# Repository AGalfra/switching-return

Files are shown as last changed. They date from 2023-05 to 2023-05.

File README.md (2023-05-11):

# Conmutador de Retorno

## I. INTRODUCCIÓN
A pesar de la creciente demanda de servicios FTTH (Fiber To The Home), se puede decir que hoy en
día el despliegue de redes de HFC (Hybrid Fibre Coaxial) puede considerarse bastante masivo.
Para mantener los estándares de salud de red que la empresa exige y mejorar la experiencia del
cliente es que se trabaja exhaustivamente en tareas de mantenimiento preventivo.
El mayor problema de este tipo de redes es debido a la interferencia generada por las instalaciones
domiciliarias defectuosas y sobre todo a la alta tasa de conexiones clandestinas que son las mayores
generadoras de interferencias. Debido a esto es que aproximadamente el 90% de las intervenciones
en este tipo de redes es por los problemas antes mencionados. La cual es una tarea que demanda
demasiado tiempo y costo operativo.
Es por ello, que se propone el diseño de una herramienta que ayude a optimizar los tiempos de
trabajo y agilizar las tareas de búsqueda de interferencias.

## II. OBJETIVO
Diseño de un dispositivo que será utilizado como una herramienta adicional y complementaria a las
existentes para facilitar las tareas de mantenimiento en redes HFC, específicamente simplificar la
búsqueda de ruido y detección de interferencias en la banda de UPSTREAM en los nodos.

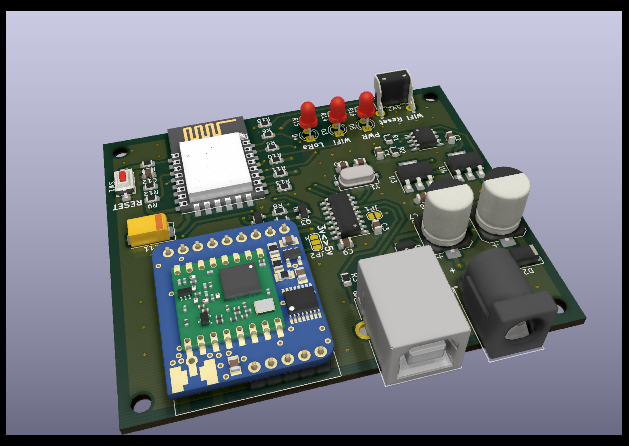
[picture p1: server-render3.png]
server

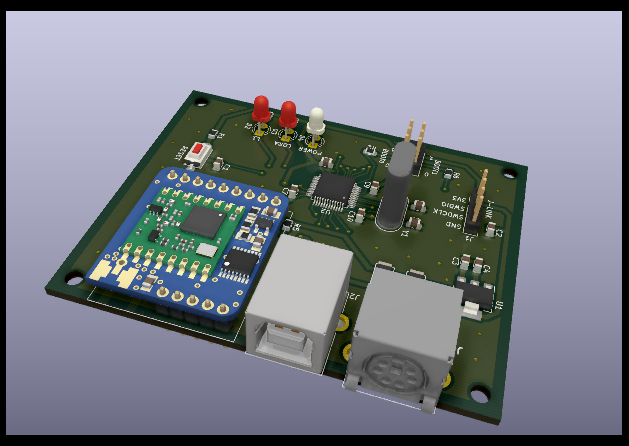
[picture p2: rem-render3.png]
remoto


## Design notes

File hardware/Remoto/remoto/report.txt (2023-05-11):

Anotado 1M como R7
Anotado Boot_Selector como J3
Anotado Mini-DIN-6 como J4
Anotado 10K como R1
Anotado 100K como R2
Anotado 20R como R3
Anotado 20R como R4
Anotado 10K como R5
Anotado 100K como R6
Anotado USB_B como J2
Anotado 1K como R8
Anotado 1K como R9
Anotado 1K como R10
Anotado SW_Reset como SW1
Anotado AMS1117-3.3 como U1
Anotado STM32F103C8Tx como U2
Anotado 8MHz como Y1
Anotado 105 como C1
Anotado J-Link como J1
Anotado RFM95W como IC1
Anotado LED como D4
Anotado LED como D3
Anotado LED como D2
Anotado SS14 como D1
Anotado 104 como C10
Anotado 104 como C9
Anotado 104 como C8
Anotado 104 como C7
Anotado 22pF como C6
Anotado 22pF como C5
Anotado C como C4
Anotado C como C3
Anotado 104 como C2

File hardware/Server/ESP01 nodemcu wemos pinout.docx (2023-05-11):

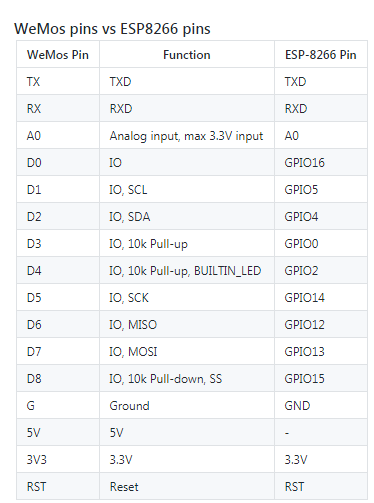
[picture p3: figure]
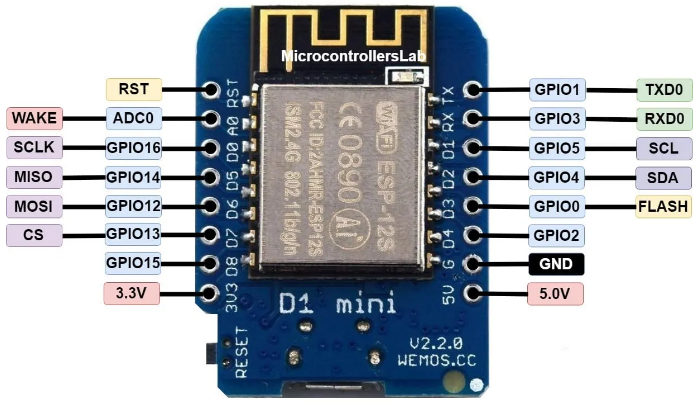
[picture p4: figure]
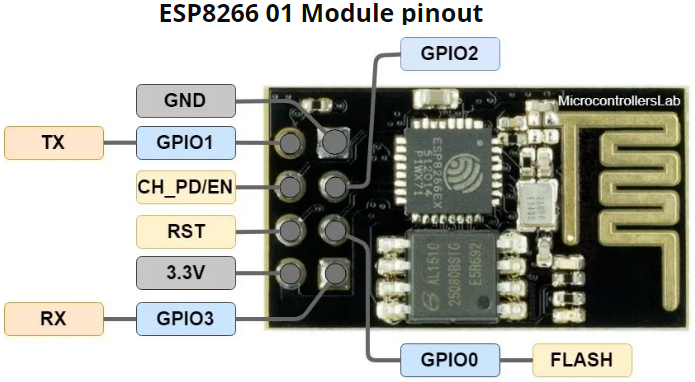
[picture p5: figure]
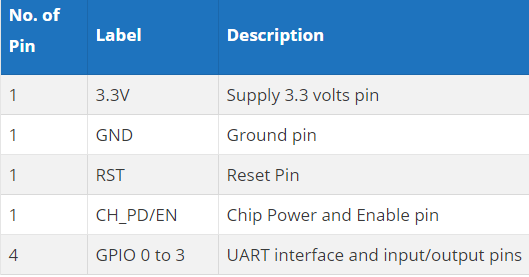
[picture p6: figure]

https://www.luisllamas.es/detalles-del-esp8266-diferencias-con-arduino/

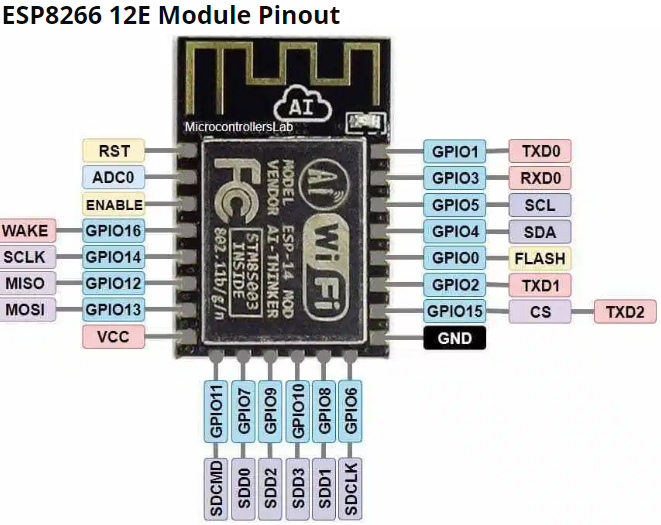
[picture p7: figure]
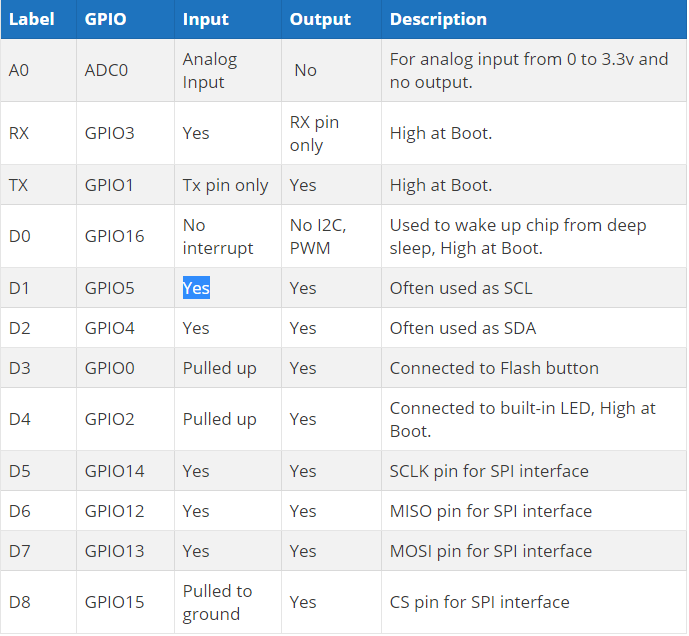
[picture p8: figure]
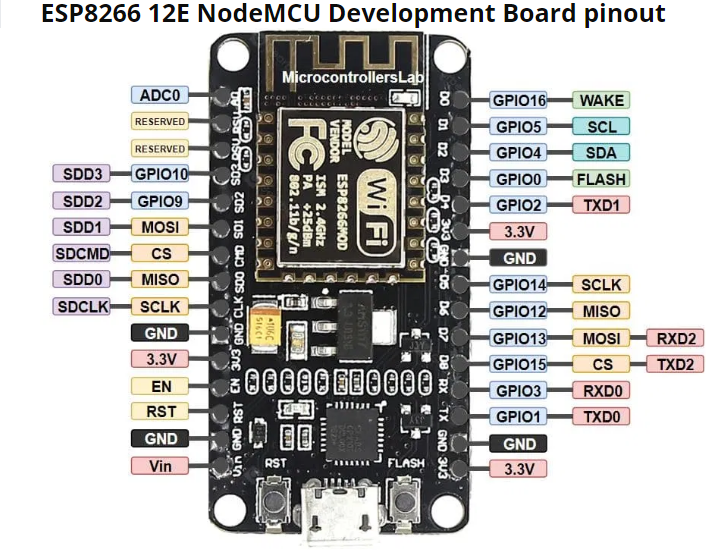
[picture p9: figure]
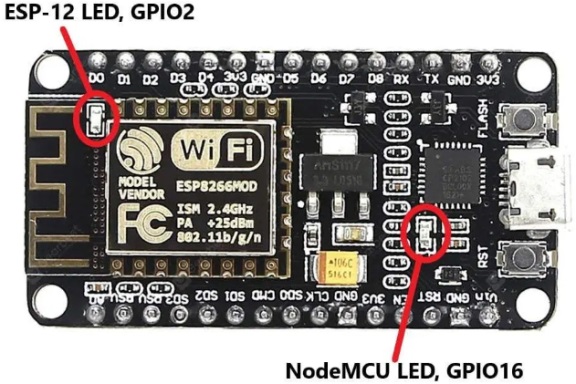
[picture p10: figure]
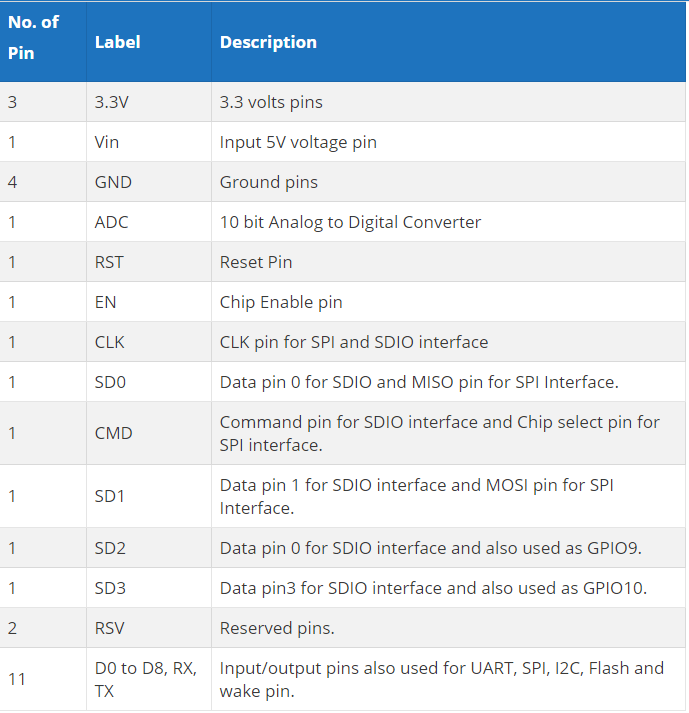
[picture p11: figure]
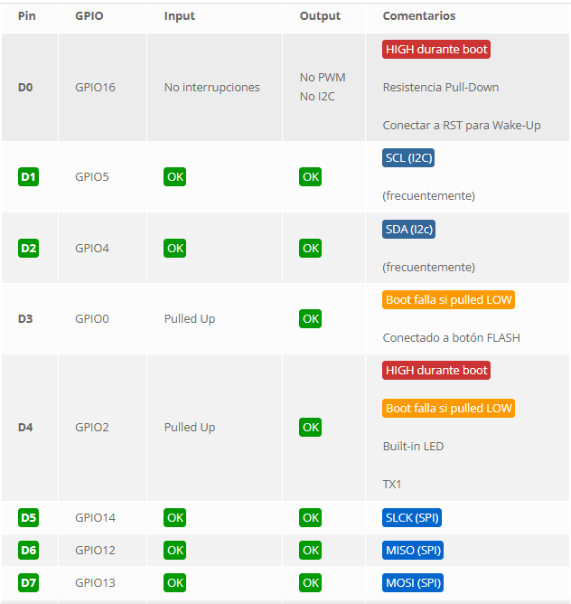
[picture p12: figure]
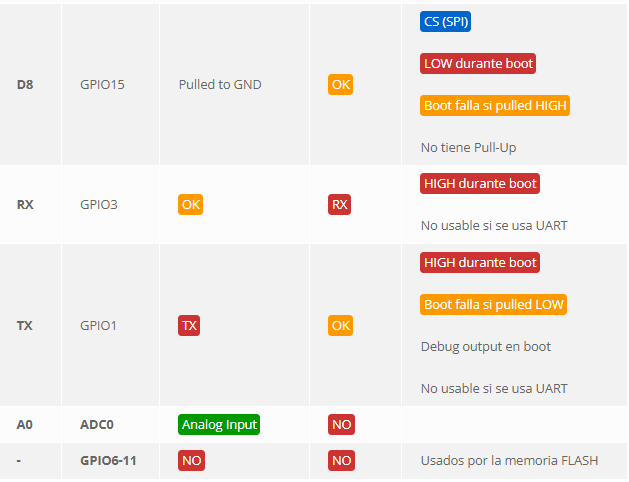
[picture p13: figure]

ESP32 de 30 pines LuaNode:

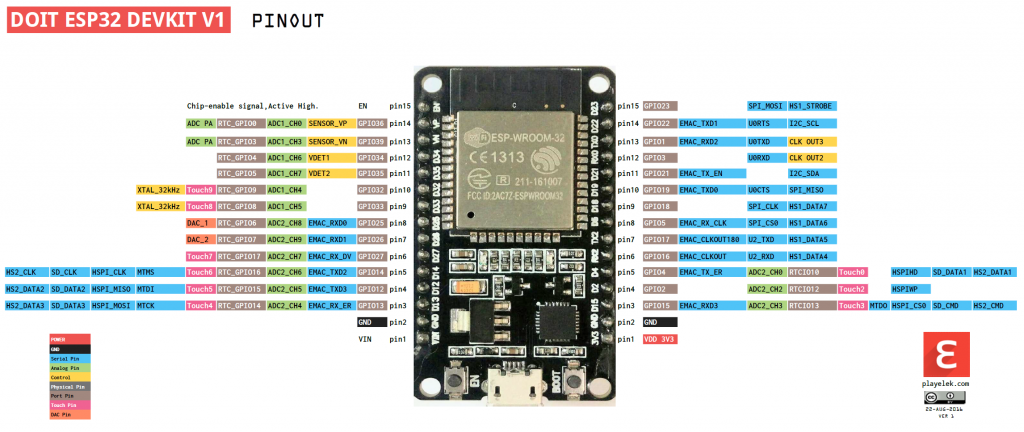
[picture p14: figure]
Mapeo de pines ESP32

Algunos pines GPIO se utilizan para configurar el cargador de arranque o el modo de flasheo de ESP32 durante el flasheo o la carga de arranque de la aplicación.

- GPIO0
- GPIO2
- GPIO4
- GPIO5 (debe estar ALTO durante el arranque)
- GPIO12 (debe estar BAJO durante el arranque)
- GPIO15 (debe ser ALTO durante el arranque)

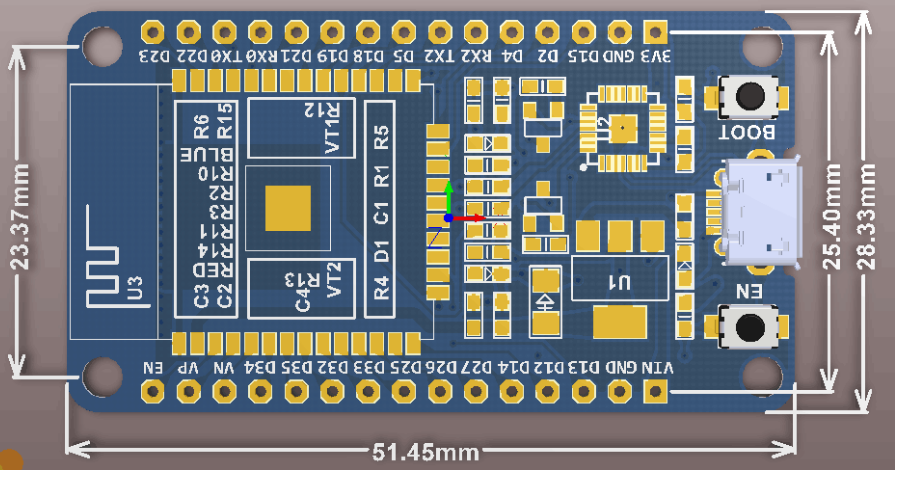
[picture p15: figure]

ESquematico: https://www.dropbox.com/s/jefwxxtufgwg0ex/esp32_Schematic%20Prints.pdf?dl=0

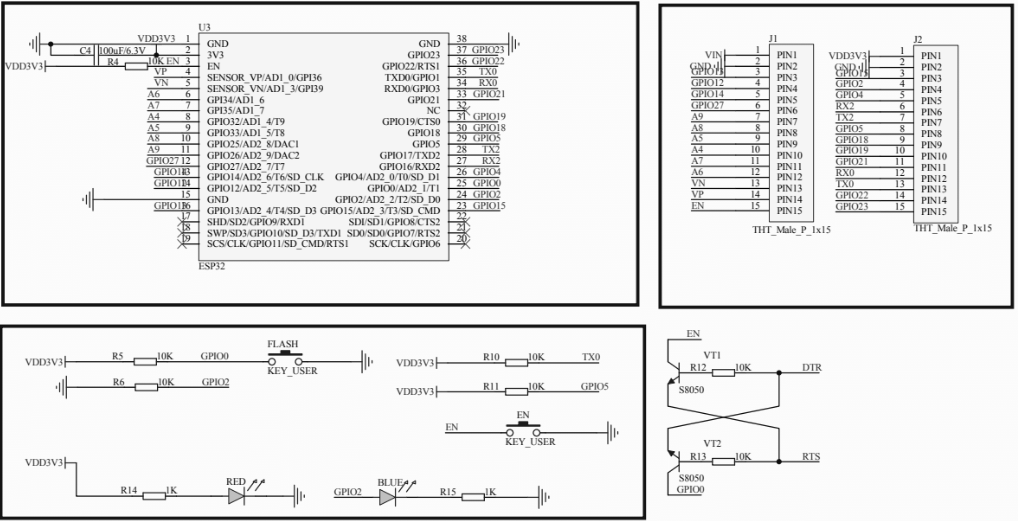
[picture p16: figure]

ESP32s – 38 PINES

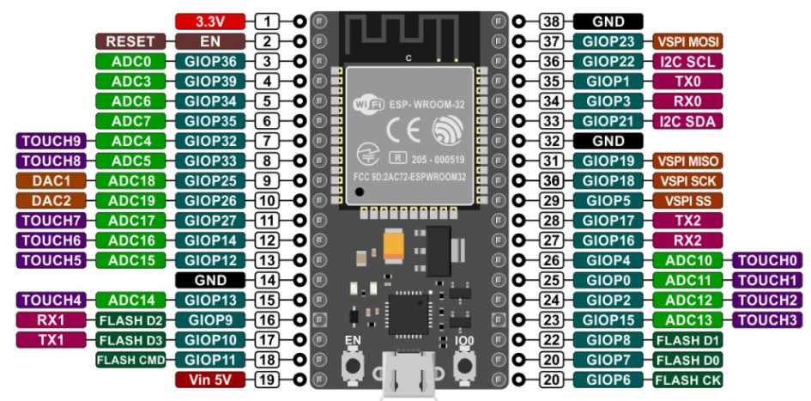
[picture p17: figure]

Configuración de Pines y asociación en el ARDUINO IDE

Alias | GPIO | Alias | GPIO | Alias | GPIO
D0 | 3 | D6 | 12 | D12 | 12
D1 | 1 | D7 | 13 | D13 | 14
D2 | 16 | D8 | 0 | D14 | 4
D3 | 5 | D9 | 2 | D15 | 5
D4 | 4 | D10 | 15
D5 | 14 | D11 | 13

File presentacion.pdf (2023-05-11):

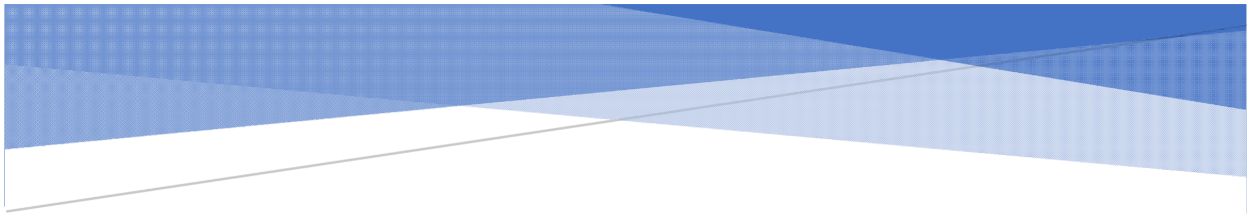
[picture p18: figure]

# CONMUTADOR DE RETORNO

Integrante:

ALEJANDRO GALFRASCOLI LEGAJO: 43029

### Descripción breve

El presente documento propone una solución a una problemática recurrente en las tareas de mantenimiento de redes HFC empleadas por Telecom S.A.

Universidad Tecnológica Nacional - Facultad Regional Córdoba | 1

# Conmutador de Retorno

I. INTRODUCCIÓN
A pesar de la creciente demanda de servicios FTTH (Fiber To The Home), se puede decir que hoy en día el despliegue de redes de HFC (Hybrid Fibre Coaxial) puede considerarse bastante masivo.
Para mantener los estándares de salud de red que la empresa exige y mejorar la experiencia del cliente es que se trabaja exhaustivamente en tareas de mantenimiento preventivo.
El mayor problema de este tipo de redes es debido a la interferencia generada por las instalaciones domiciliarias defectuosas y sobre todo a la alta tasa de conexiones clandestinas que son las mayores generadoras de interferencias. Debido a esto es que aproximadamente el 90% de las intervenciones en este tipo de redes es por los problemas antes mencionados. La cual es una tarea que demanda demasiado tiempo y costo operativo.
Es por ello, que se propone el diseño de una herramienta que ayude a optimizar los tiempos de trabajo y agilizar las tareas de búsqueda de interferencias.

II. OBJETIVO
Diseño de un dispositivo que será utilizado como una herramienta adicional y complementaria a las existentes para facilitar las tareas de mantenimiento en redes HFC, específicamente simplificar la búsqueda de ruido y detección de interferencias en la banda de UPSTREAM en los nodos.

III. ALCANCE Y SECTORES DE APLICACIÓN
El dispositivo propuesto puede ser utilizado en todas las redes HFC. Se muestra a continuación en la figura 1 un modelo de nodo óptico Cisco [1] sobre el que debe ser instalado el dispositivo propuesto, y en la figura 2 vemos esquemáticamente como es el módulo de RF de este nodo.

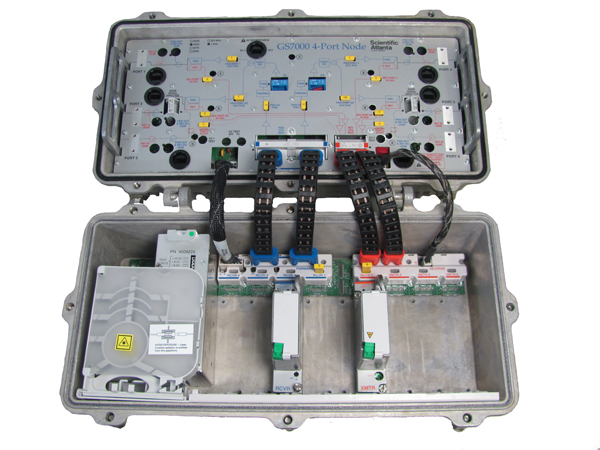
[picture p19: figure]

Figura 1: Nodo óptico Cisco modelo GS7000

Universidad Tecnológica Nacional - Facultad Regional Córdoba | 2

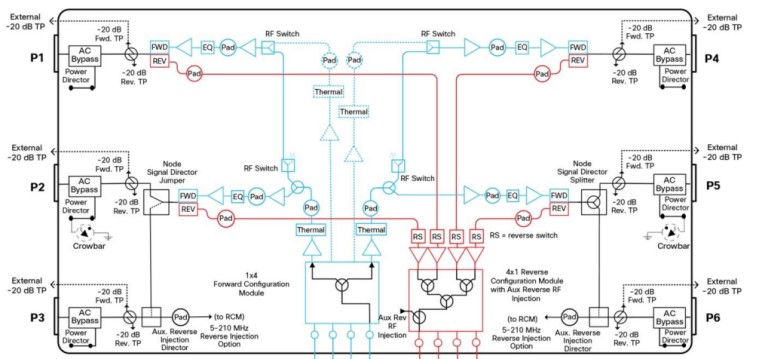
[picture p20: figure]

Figura 2: esquema módulo de RF de GS7000

IV. DESARROLLO
Se pretende que el dispositivo realice la conexión o desconexión de cualquiera de los Pad de entrada de UPSTREAM del nodo de manera remota y a petición del técnico según sea necesario, permitiendo anular cualquier interferencia que esté presente en los puertos del nodo. De esta manera es posible verificar de manera individual la interferencia que aporta cada puerto en la banda de UPSTREAM.
Este dispositivo llamado en adelante “Conmutador de Retorno” está pensado como una herramienta complementaria para agilizar la búsqueda de ruido, ya que en todo momento se puede determinar exactamente en qué puerto se está generando el mayor ingreso de ruido.
Es de suma utilidad en nodos no segmentados, ya que en ellos la suma de ruido de todos los puertos dificulta su búsqueda con los sistemas de monitoreo actualmente en uso.
También es muy útil en situaciones en las que aparecen interferencias de manera aleatoria o esporádica, ya que permite remotamente el apagado de los puertos para su posterior verificación con software de monitoreo.
O en lugares donde las interferencias aparecen en zonas y horarios de difícil acceso, con este dispositivo es posible acotar en gran medida el problema y de manera remota.

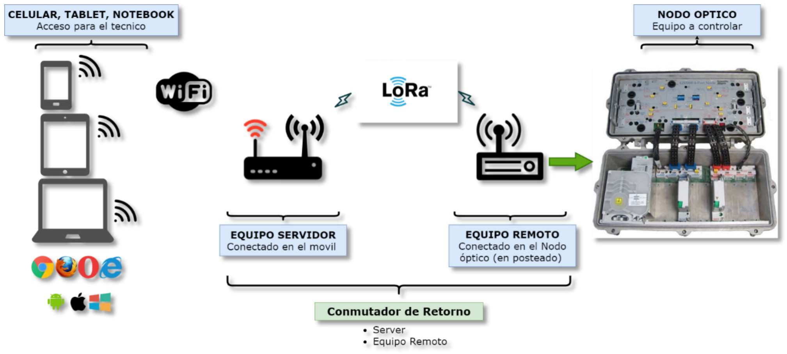
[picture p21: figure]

Universidad Tecnológica Nacional - Facultad Regional Córdoba | 3

Figura 3: Esquema del dispositivo propuesto
Como se puede apreciar en la figura 3 se muestra un esquema general del dispositivo propuesto, el
cual consitiría en un EQUIPO REMOTO que sería instalado en el nodo óptico (generalmente se encuentra en altura en el posteado), este equipo recibiría los comandos para conectar o desconectar cada uno de los puertos del nodo, dichos comando serían enviados desde un EQUIPO SERVIDOR, éste último sería colocado en el móvil de la cuadrilla de mantenimiento y de esta manera permitiría la libre movilidad de los tecnicos por toda la extensión del nodo.
El equipo servidor proveerá de conectividad WiFi 802.11 b/g/n y será un servidor web que brindará una pagina web desde la que será posible ver el estado y operar al equipo remoto.
Al ser a traves de una pagina web permite que el tecnico pueda conectarse desde una notebook, tablet o cualquier telefono celular y accesible desde cualquier tipo de navegador, independizandonos también del sistema operativo que este posea.
Esta previsto que entre el EQUIPO SERVIDOR y el EQUIPO REMOTO la conexión sea a través de LoRa (Long Range), que es una tecnólogia de comunicaciones LP-WAN de bajo costo, bajo consumo, gran rango y sobre todo operan en banda no licenciada.

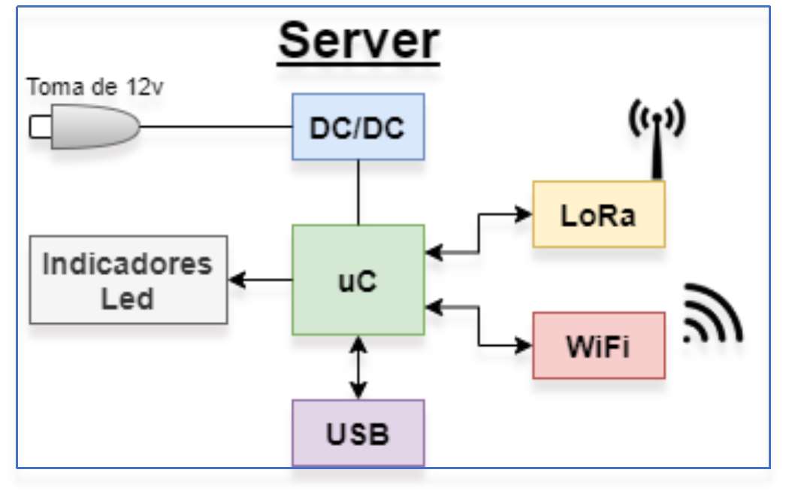
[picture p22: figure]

Figura 4: Esquema – Equipo Servidor

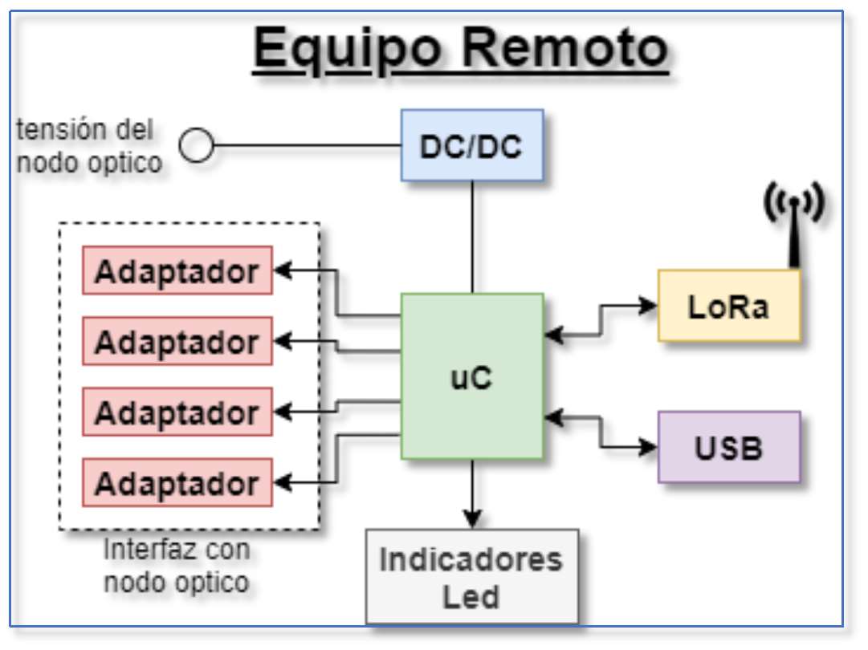
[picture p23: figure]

Figura 5: Esquema – Equipo Remoto
V. REFERENCIAS
[1] https://www.cisco.com/c/en/us/products/video/gs7000-node/index.html

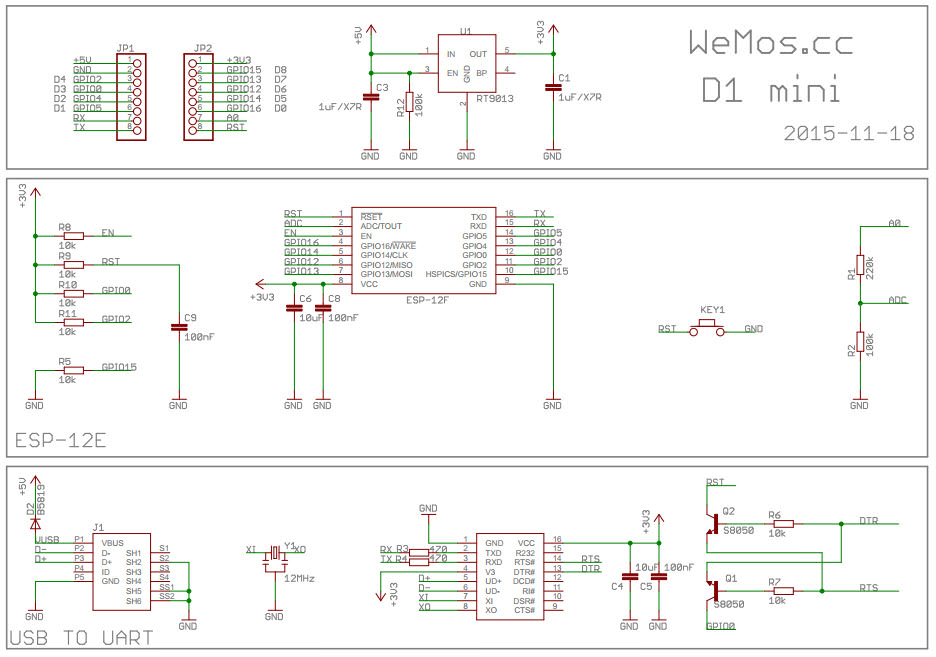
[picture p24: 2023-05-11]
hardware/Server/wemos D1mini esquematico.jpg

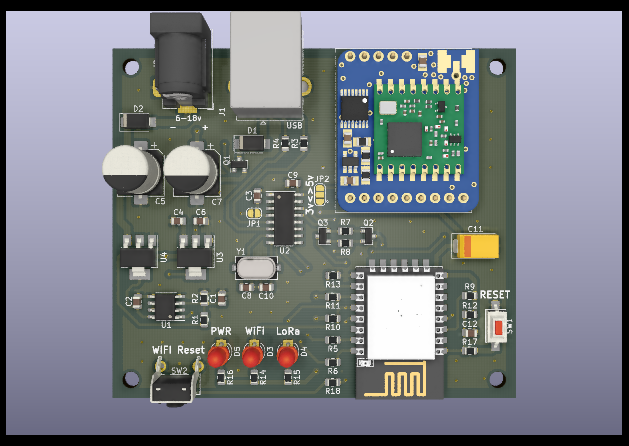
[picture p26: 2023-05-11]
server-render1.png

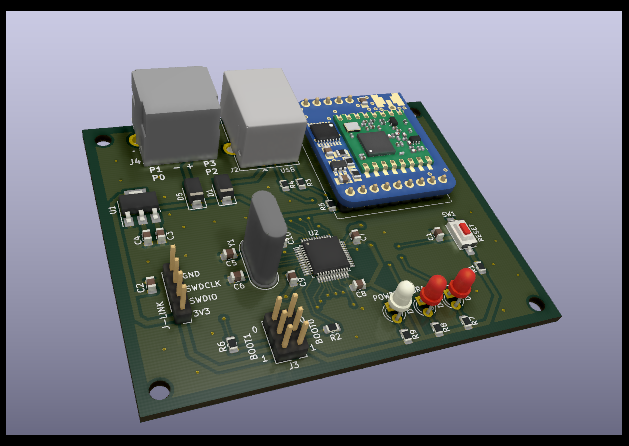
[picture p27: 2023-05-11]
rem-render2.png

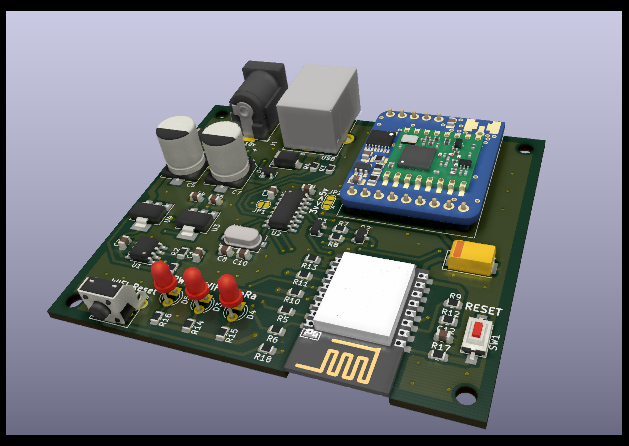
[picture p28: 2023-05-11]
server-render2.png

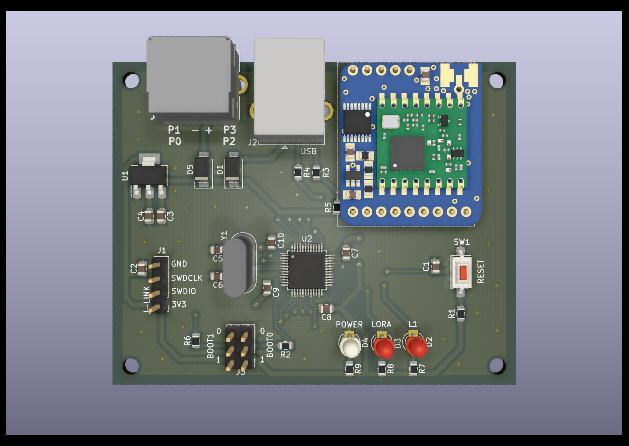
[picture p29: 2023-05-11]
rem-render1.png

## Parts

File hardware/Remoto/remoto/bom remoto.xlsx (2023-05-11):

LISTA DE COMPONENTES - EQUIPO REMOTO
ref | value | footprint | part | Columna1
C1 | 104 | Capacitor_SMD:C_0805_2012Metric | C | 1.5
C10 | 104 | Capacitor_SMD:C_0805_2012Metric | C | 1.5
C2 | 104 | Capacitor_SMD:C_0805_2012Metric | C | 1.5
C3 | 22uF | Capacitor_SMD:C_0805_2012Metric | C | 1.5
C4 | 10uF | Capacitor_SMD:C_0805_2012Metric | C | 1.5
C5 | 22pF | Capacitor_SMD:C_0805_2012Metric | C | 1.5
C6 | 22pF | Capacitor_SMD:C_0805_2012Metric | C | 1.5
C7 | 104 | Capacitor_SMD:C_0805_2012Metric | C | 1.5
C8 | 104 | Capacitor_SMD:C_0805_2012Metric | C | 1.5
C9 | 104 | Capacitor_SMD:C_0805_2012Metric | C | 1.5
D1 | SS14 | Diode_SMD:D_SMA | D_Schottky | 2.3
D2 | LED | LED_THT:LED_D3.0mm | LED | 1.26
D3 | LED | LED_THT:LED_D3.0mm | LED | 1.26
D4 | LED | LED_THT:LED_D3.0mm_Clear | LED | 1.26
D5 | SS14 | Diode_SMD:D_SMA | D_Schottky | 2.3
IC1 | RFM95W | RFM95W:RFM95W | RFM95W | 2036
J1 | J-Link | PinHeader_1x04_P2.54mm_Vertical | Conn_01x04 | 30
J2 | USB_B | Modulos Varios:conector_USB_tipoB | USB_B | 76
J3 | Boot_Selector | PinHeader_2x03_P2.54mm_Vertical | Conn_02x03_Odd_Even | 0
J4 | Mini-DIN-6 | Modulos Varios:Mini-Din-6 | Mini-DIN-6 | 90
R1 | 10K | Resistor_SMD:R_0805_2012Metric | R | 1.25
R2 | 100K | Resistor_SMD:R_0805_2012Metric | R | 1.25
R3 | 20R | Resistor_SMD:R_0805_2012Metric | R | 1.25
R4 | 20R | Resistor_SMD:R_0805_2012Metric | R | 1.25
R5 | 5K1 | Resistor_SMD:R_0805_2012Metric | R | 1.25
R6 | 100K | Resistor_SMD:R_0805_2012Metric | R | 1.25
R7 | 1K | Resistor_SMD:R_0805_2012Metric | R | 1.25
R8 | 1K | Resistor_SMD:R_0805_2012Metric | R | 1.25
R9 | 1K | Resistor_SMD:R_0805_2012Metric | R | 1.25
SW1 | SW_Reset | Button_Switch_SMD:SW_SPST_CK_RS282G05A3 | SW_Push | 3
U1 | AMS1117-3.3 | Package_TO_SOT_SMD:SOT-223-3_TabPin2 | AMS1117-3.3 | 3.1
U2 | STM32F103C8Tx | Package_QFP:LQFP-48_7x7mm_P0.5mm | STM32F103C8Tx | 350
Y1 | 8MHz | Crystal:Crystal_HC18-U_Vertical | Crystal | 15
 |  | Antena |  | 1500
 |  | Conector SMA |  | 255
 |  | Gabinete |  | 800
 |  | Placa |  | 600
 |  |  |  | 5792.73

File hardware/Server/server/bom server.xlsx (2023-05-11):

LISTA DE COMPONENTES - EQUIPO SERVIDOR
ref | value | footprint | part | Precio Unitario
C1 | 100nF | Capacitor_SMD:C_0805_2012Metric | C | 1.5
C10 | 22pF | Capacitor_SMD:C_0805_2012Metric | C | 1.5
C11 | 100uF | Capacitor_Tantalum_SMD:CP_EIA-7343-31_Kemet-D | C | 22
C12 | 100nF | Capacitor_SMD:C_0805_2012Metric | C | 1.5
C2 | 100nF | Capacitor_SMD:C_0805_2012Metric | C | 1.5
C3 | 10nF | Capacitor_SMD:C_0805_2012Metric | C | 1.5
C4 | 10uF | Capacitor_SMD:C_0805_2012Metric | C | 1.5
C5 | 47uF | Capacitor_SMD:CP_Elec_8x10.5 | C | 10.3
C6 | 10uF | Capacitor_SMD:C_0805_2012Metric | C | 1.5
C7 | 47uF | Capacitor_SMD:CP_Elec_8x10.5 | C | 10.3
C8 | 22pF | Capacitor_SMD:C_0805_2012Metric | C | 1.5
C9 | 100nF | Capacitor_SMD:C_0805_2012Metric | C | 1.5
D1 | SS14 | Diode_SMD:D_SMA | D_Schottky | 2.3
D2 | M7 | Diode_SMD:D_SMA | B120-E3 | 1.5
D3 | LED | LED_THT:LED_D3.0mm | LED | 1.26
D4 | LED | LED_THT:LED_D3.0mm | LED | 1.26
D5 | LED | LED_THT:LED_D3.0mm | LED | 1.26
IC1 | RFM95W | RFM95W:RFM95W | RFM95W | 2036
J1 | USB_B | Modulos Varios:conector_USB_tipoB | USB_B | 76
J2 | Jack_Switch | Modulos Varios:conector_jack_2.1mm | Barrel_Jack_Switch | 11
Q1 | AO3415 | Package_TO_SOT_SMD:SOT-23 | AO3401A | 4
Q2 | BC817 | Package_TO_SOT_SMD:SOT-23 | BC817 | 2.2
Q3 | BC817 | Package_TO_SOT_SMD:SOT-23 | BC817 | 2.2
R1 | 10K | Resistor_SMD:R_0805_2012Metric | R | 1.25
R10 | 10K | Resistor_SMD:R_0805_2012Metric | R | 1.25
R11 | 10K | Resistor_SMD:R_0805_2012Metric | R | 1.25
R12 | 10K | Resistor_SMD:R_0805_2012Metric | R | 1.25
R13 | 10K | Resistor_SMD:R_0805_2012Metric | R | 1.25
R14 | 470R | Resistor_SMD:R_0805_2012Metric | R | 1.25
R15 | 470R | Resistor_SMD:R_0805_2012Metric | R | 1.25
R16 | 470R | Resistor_SMD:R_0805_2012Metric | R | 1.25
R17 | 470R | Resistor_SMD:R_0805_2012Metric | R | 1.25
R18 | 470R | Resistor_SMD:R_0805_2012Metric | R | 1.25
R2 | 10K | Resistor_SMD:R_0805_2012Metric | R | 1.25
R3 | 22R | Resistor_SMD:R_0805_2012Metric | R | 1.25
R4 | 22R | Resistor_SMD:R_0805_2012Metric | R | 1.25
R5 | 470R | Resistor_SMD:R_0805_2012Metric | R | 1.25
R6 | 470R | Resistor_SMD:R_0805_2012Metric | R | 1.25
R7 | 12K | Resistor_SMD:R_0805_2012Metric | R | 1.25
R8 | 12K | Resistor_SMD:R_0805_2012Metric | R | 1.25
R9 | 10K | Resistor_SMD:R_0805_2012Metric | R | 1.25
SW1 | SW_Reset | Button_Switch_SMD | SW_Push | 3
SW2 | SW_borrado | Button_Switch_THT_Angled | SW_Push | 3.5
U1 | LM358 | Package_SO:SOIC-8_3.9x4.9mm_P1.27mm | LM358 | 7
U2 | CH340G | Package_SO:SOIC-16_3.9x9.9mm_P1.27mm | CH340G | 80
U3 | AMS1117-3.3 | Package_TO_SOT_SMD:SOT-223-3_TabPin2 | AMS1117-3.3 | 3.1
U4 | AMS1117-5.0 | Package_TO_SOT_SMD:SOT-223-3_TabPin2 | AMS1117-5.0 | 3.1
U5 | ESP-12F | ESP8266:ESP-12E_SMD | ESP-12F | 200
Y1 | 12MHz | Modulos Varios:cristal_SMD_ABLS7M2_7x4.1mm | Crystal | 15
 |  | Antena |  | 1500
 |  | Conector SMA |  | 255
 |  | Gabinete |  | 800
 |  | Placa |  | 600
 |  |  |  | 5687.28

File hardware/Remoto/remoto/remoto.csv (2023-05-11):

Comment | Designator | Footprint
SW_Reset | SW1 | SW_SPST_CK_RS282G05A3
SS14 | D5,D1 | D_SMA
MountingHole | H4,H3,H2,H1 | MountingHole_3mm
8MHz | Y1 | Crystal_HC18-U_Vertical
STM32F103C8T6 | U2 | LQFP-48_7x7mm_P0.5mm
AMS1117-3.3 | U1 | SOT-223-3_TabPin2
1K | R9,R8,R7 | R_0805_2012Metric
100K | R6,R2 | R_0805_2012Metric
10K | R5,R1 | R_0805_2012Metric
20R | R4,R3 | R_0805_2012Metric
Mini-DIN-6 | J4 | Mini-Din-6
Boot_Selector | J3 | PinHeader_2x03_P2.54mm_Vertical
USB_B | J2 | conector_USB_tipoB
J-Link | J1 | PinHeader_1x04_P2.54mm_Vertical
RFM95W | IC1 | RFM95W
LED | D4 | LED_D3.0mm_Clear
LED | D3,D2 | LED_D3.0mm
104 | C10,C9,C8,C7,C2 | C_0805_2012Metric
22pF | C6,C5 | C_0805_2012Metric
10uF | C4 | C_0805_2012Metric
22uF | C3 | C_0805_2012Metric
105 | C1 | C_0805_2012Metric

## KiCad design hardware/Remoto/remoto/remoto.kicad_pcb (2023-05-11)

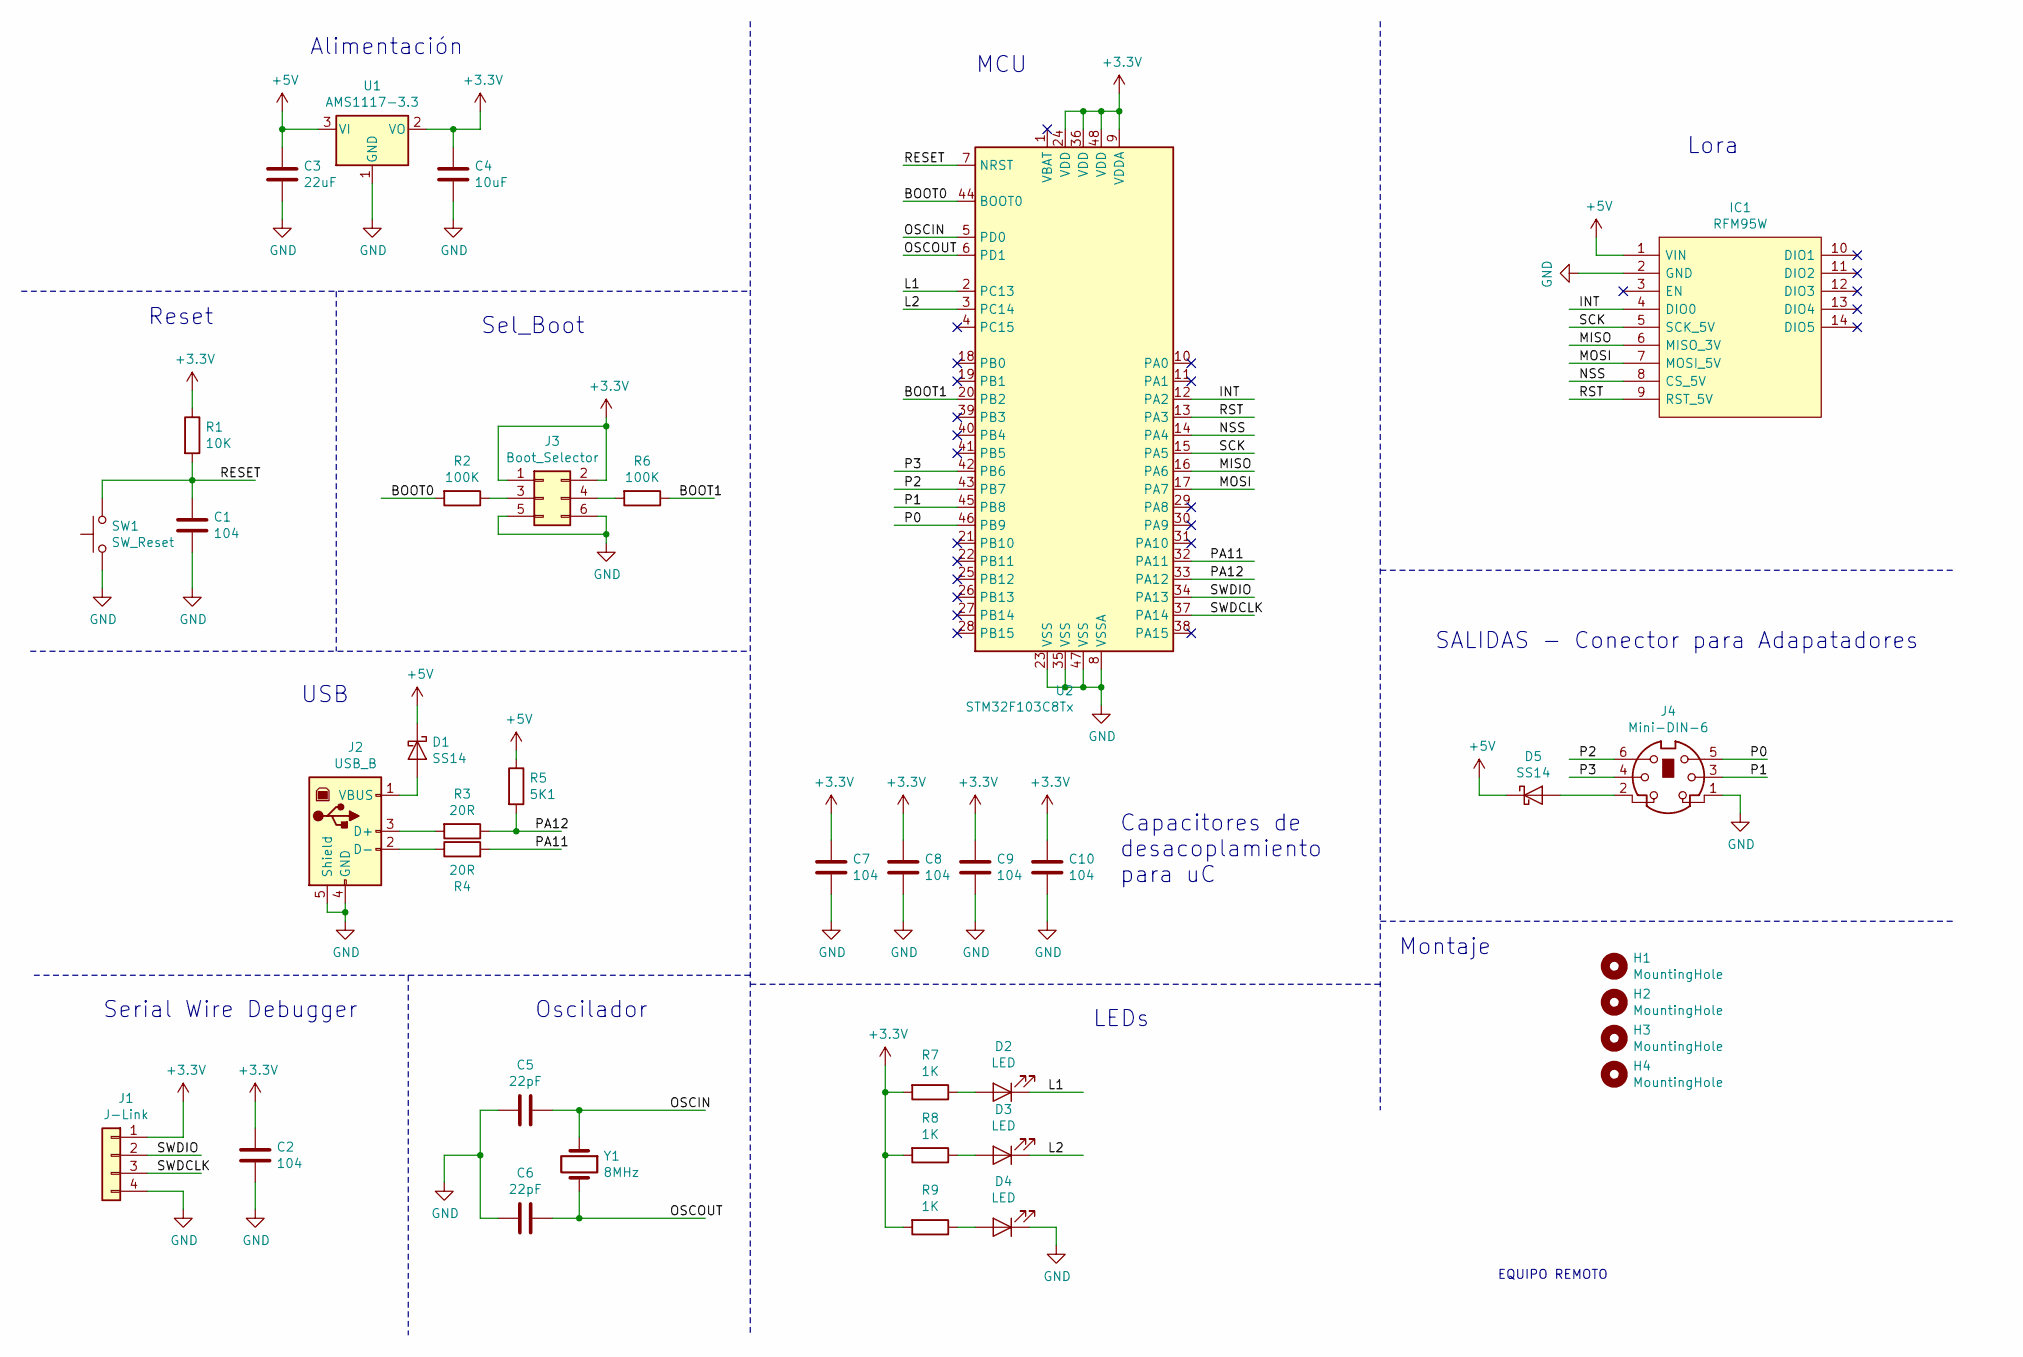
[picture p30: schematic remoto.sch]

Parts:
C1, C2, C7, C8, C9, C10: 104; C_0805_2012Metric
C3: 22uF; C_0805_2012Metric
C4: 10uF; C_0805_2012Metric
C5, C6: 22pF; C_0805_2012Metric
D1, D5: SS14; D_SMA
D2, D3: LED; LED_D3.0mm
D4: LED; LED_D3.0mm_Clear
H1, H2, H3, H4: MountingHole; MountingHole_3mm
IC1: RFM95W; Mouser Part Number 485-3072
J1: J-Link; PinHeader_1x04_P2.54mm_Vertical
J2: USB_B; conector_USB_tipoB
J3: Boot_Selector; PinHeader_2x03_P2.54mm_Vertical
J4: Mini-DIN-6; Mini-Din-6
R1: 10K; R_0805_2012Metric
R2, R6: 100K; R_0805_2012Metric
R3, R4: 20R; R_0805_2012Metric
R5: 5K1; R_0805_2012Metric
R7, R8, R9: 1K; R_0805_2012Metric
SW1: SW_Reset; SW_SPST_CK_RS282G05A3
U1: AMS1117-3.3; SOT-223-3_TabPin2
U2: STM32F103C8Tx; LQFP-48_7x7mm_P0.5mm
Y1: 8MHz; Crystal_HC18-U_Vertical

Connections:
+3V3: C2.1, C4.1, C7.1, C8.1, C9.1, C10.1, J1.1, J3.1, J3.2, R1.1, R7.2, R8.2, R9.2, U1.2 (VO), U2.9 (VDDA), U2.24 (VDD), U2.36 (VDD), U2.48 (VDD)
+5V: C3.1, D1.1 (K), D5.1 (K), IC1.1 (VIN), R5.1, U1.3 (VI)
/BOOT0: R2.2, U2.44 (BOOT0)
/BOOT1: R6.1, U2.20 (PB2)
/INT: IC1.4 (DIO0), U2.12 (PA2)
/L1: D2.1 (K), U2.2 (PC13)
/L2: D3.1 (K), U2.3 (PC14)
/MISO: IC1.6 (MISO_3V), U2.16 (PA6)
/MOSI: IC1.7 (MOSI_5V), U2.17 (PA7)
/NSS: IC1.8 (CS_5V), U2.14 (PA4)
/OSCIN: C5.1, U2.5 (PD0), Y1.1
/OSCOUT: C6.1, U2.6 (PD1), Y1.2
/P0: J4.5, U2.46 (PB9)
/P1: J4.3, U2.45 (PB8)
/P2: J4.6, U2.43 (PB7)
/P3: J4.4, U2.42 (PB6)
/PA11: R4.2, U2.32 (PA11)
/PA12: R3.1, R5.2, U2.33 (PA12)
/RESET: C1.1, R1.2, SW1.2, U2.7 (NRST)
/RST: IC1.9 (RST_5V), U2.13 (PA3)
/SCK: IC1.5 (SCK_5V), U2.15 (PA5)
/SWDCLK: J1.3, U2.37 (PA14)
/SWDIO: J1.2, U2.34 (PA13)
GND: C1.2, C2.2, C3.2, C4.2, C5.2, C6.2, C7.2, C8.2, C9.2, C10.2, D4.1 (K), IC1.2 (GND), J1.4, J2.4 (GND), J2.5 (Shield), J3.5, J3.6, J4.1, SW1.1, U1.1 (GND), U2.8 (VSSA), U2.23 (VSS), U2.35 (VSS), U2.47 (VSS)
unnamed: D1.2 (A), J2.1 (VBUS)
unnamed: D2.2 (A), R7.1
unnamed: D3.2 (A), R8.1
unnamed: D4.2 (A), R9.1
unnamed: D5.2 (A), J4.2
unnamed: J2.2 (D-), R4.1
unnamed: J2.3 (D+), R3.2
unnamed: J3.3, R2.1
unnamed: J3.4, R6.2

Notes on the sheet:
Serial Wire Debugger
Reset
USB
Alimentación
Sel_Boot
Oscilador
MCU
LEDs
Capacitores de desacoplamiento para uC
Montaje
SALIDAS - Conector para Adapatadores
EQUIPO REMOTO
Lora

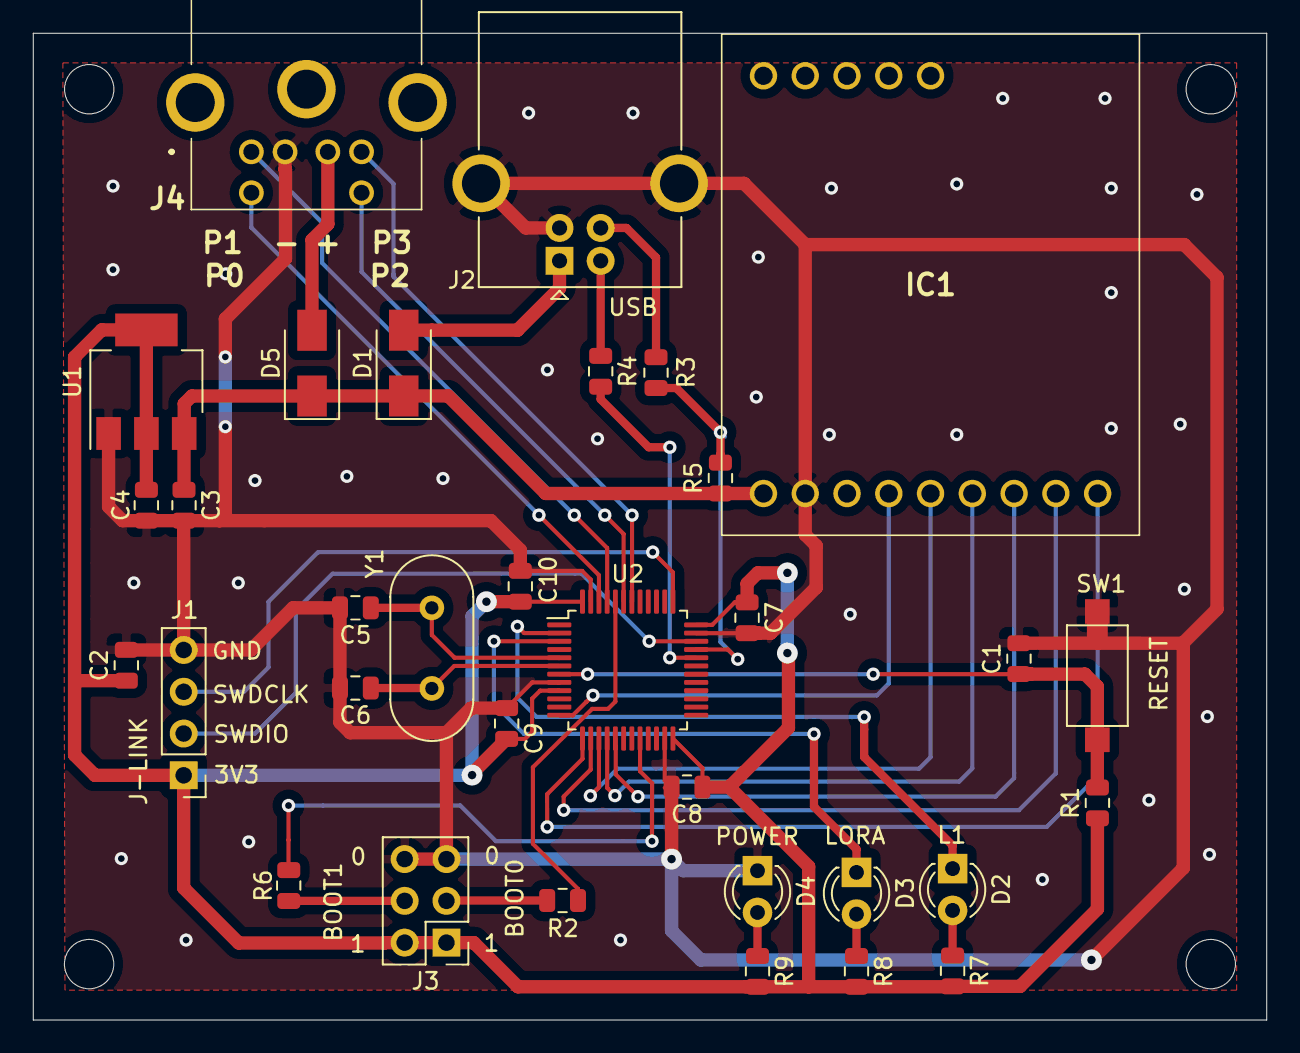
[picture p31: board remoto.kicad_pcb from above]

Board: 2 copper layers, 75.0 x 60.0 mm, 37 parts (0 on the bottom side), 33 nets.

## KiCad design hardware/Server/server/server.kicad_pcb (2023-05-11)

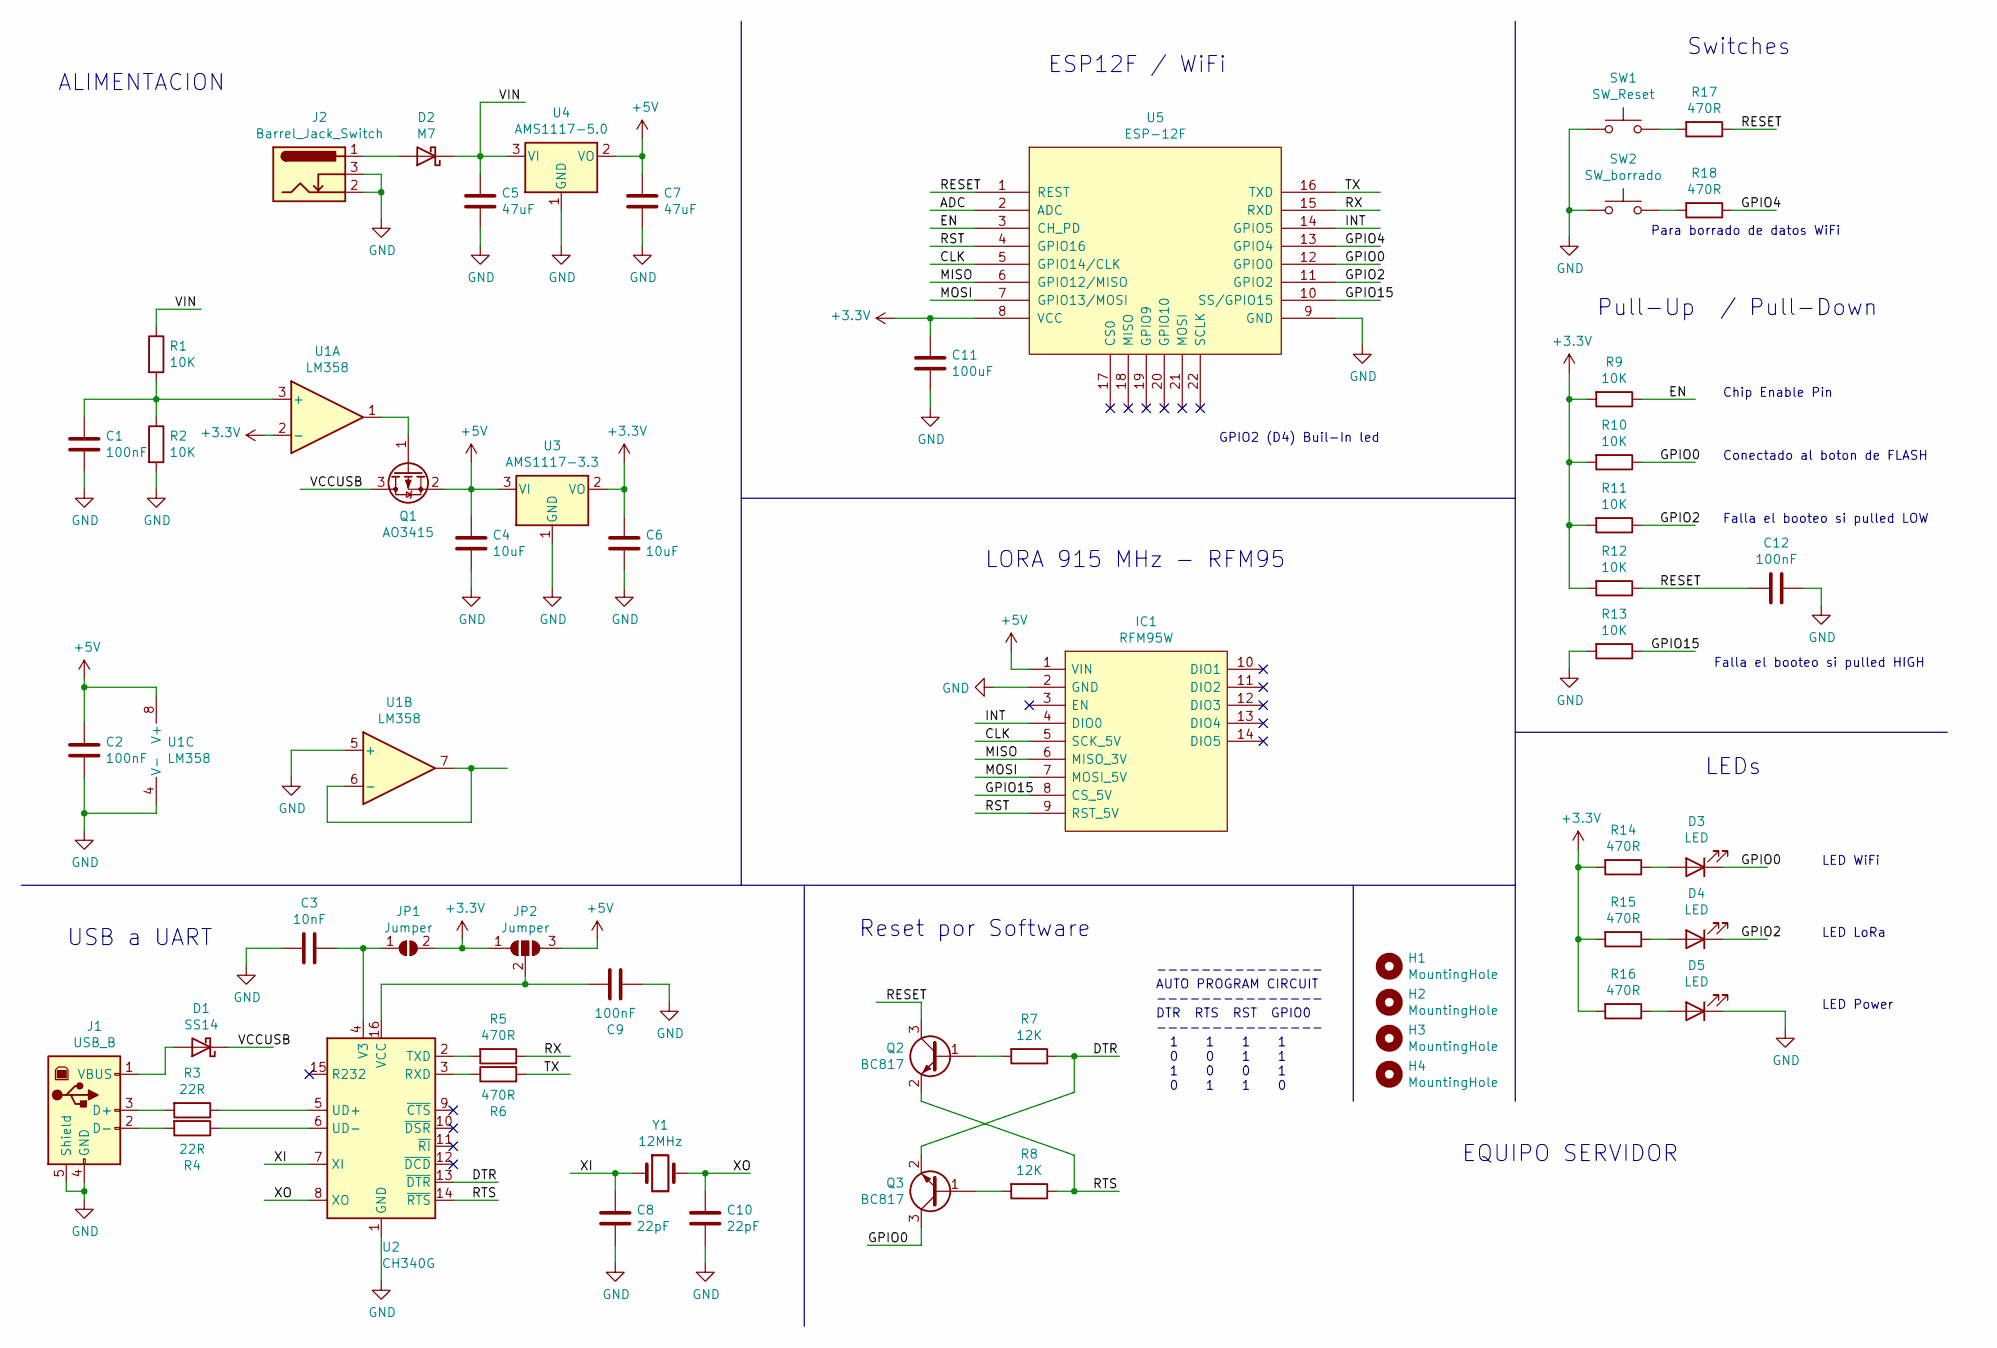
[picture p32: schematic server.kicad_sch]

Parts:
C1, C2, C9, C12: 100nF; C_0805_2012Metric
C3: 10nF; C_0805_2012Metric
C4, C6: 10uF; C_0805_2012Metric
C5, C7: 47uF; CP_Elec_8x10.5
C8, C10: 22pF; C_0805_2012Metric
C11: 100uF; CP_EIA-7343-31_Kemet-D
D1: SS14; D_SMA
D2: M7; D_SMA
D3, D4, D5: LED; LED_D3.0mm
H1, H2, H3, H4: MountingHole; MountingHole_3mm
IC1: RFM95W; Mouser Part Number 485-3072
J1: USB_B; conector_USB_tipoB
J2: Barrel_Jack_Switch; conector_jack_2.1mm
JP1: Jumper; SolderJumper-2_P1.3mm_Open_RoundedPad1.0x1.5mm
JP2: Jumper; SolderJumper-3_P1.3mm_Open_RoundedPad1.0x1.5mm
Q1: AO3415; SOT-23
Q2, Q3: BC817; SOT-23
R1, R2, R9, R10, R11, R12, R13: 10K; R_0805_2012Metric
R3, R4: 22R; R_0805_2012Metric
R5, R6, R14, R15, R16, R17, R18: 470R; R_0805_2012Metric
R7, R8: 12K; R_0805_2012Metric
SW1: SW_Reset; SW_SPST_CK_RS282G05A3
SW2: SW_borrado; SW_Tactile_SPST_Angled_PTS645Vx39-2LFS
U1: LM358; SOIC-8_3.9x4.9mm_P1.27mm
U2: CH340G; SOIC-16_3.9x9.9mm_P1.27mm
U3: AMS1117-3.3; SOT-223-3_TabPin2
U4: AMS1117-5.0; SOT-223-3_TabPin2
U5: ESP-12F; ESP-12E_SMD
Y1: 12MHz; cristal_SMD_ABLS7M2_7x4.1mm

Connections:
+3V3: C6.1, C11.1, JP1.2 (B), JP2.1 (A), R9.2, R10.2, R11.2, R12.2, R14.2, R15.2, R16.2, U1.2 (-), U3.2 (VO), U5.8 (VCC)
+5V: C2.1, C4.1, C7.1, IC1.1 (VIN), JP2.3 (B), Q1.2 (S), U1.8 (V+), U3.3 (VI), U4.2 (VO)
/ADC: U5.2 (ADC)
/CLK: IC1.5 (SCK_5V), U5.5 (GPIO14/CLK)
/DTR: Q3.2 (E), R7.1, U2.13 (~DTR)
/EN: R9.1, U5.3 (CH_PD)
/GPIO0: D3.1 (K), Q3.3 (C), R10.1, U5.12 (GPIO0)
/GPIO2: D4.1 (K), R11.1, U5.11 (GPIO2)
/GPIO4: R18.1, U5.13 (GPIO4)
/GPIO15: IC1.8 (CS_5V), R13.1, U5.10 (SS/GPIO15)
/INT: IC1.4 (DIO0), U5.14 (GPIO5)
/MISO: IC1.6 (MISO_3V), U5.6 (GPIO12/MISO)
/MOSI: IC1.7 (MOSI_5V), U5.7 (GPIO13/MOSI)
/RESET: C12.2, Q2.3 (C), R12.1, R17.1, U5.1 (REST)
/RST: IC1.9 (RST_5V), U5.4 (GPIO16)
/RTS: Q2.2 (E), R8.1, U2.14 (~RTS)
/RX: R5.1, U5.15 (RXD)
/TX: R6.2, U5.16 (TXD)
/VCCUSB: D1.1 (K), Q1.3 (D)
/VIN: C5.1, D2.1 (K), R1.1, U4.3 (VI)
/XI: C8.1, U2.7 (XI), Y1.1
/XO: C10.1, U2.8 (XO), Y1.2
GND: C1.2, C2.2, C3.2, C4.2, C5.2, C6.2, C7.2, C8.2, C9.2, C10.2, C11.2, C12.1, D5.1 (K), IC1.2 (GND), J1.4 (GND), J1.5 (Shield), J2.2, J2.3, R2.2, R13.2, SW1.1, SW2.1, U1.4 (V-), U1.5 (+), U2.1 (GND), U3.1 (GND), U4.1 (GND), U5.9 (GND)
unnamed: C1.1, R1.2, R2.1, U1.3 (+)
unnamed: C3.1, JP1.1 (A), U2.4 (V3)
unnamed: C9.1, JP2.2 (C), U2.16 (VCC)
unnamed: D1.2 (A), J1.1 (VBUS)
unnamed: D2.2 (A), J2.1
unnamed: D3.2 (A), R14.1
unnamed: D4.2 (A), R15.1
unnamed: D5.2 (A), R16.1
unnamed: J1.2 (D-), R4.2
unnamed: J1.3 (D+), R3.2
unnamed: Q1.1 (G), U1.1
unnamed: Q2.1 (B), R7.2
unnamed: Q3.1 (B), R8.2
unnamed: R3.1, U2.5 (UD+)
unnamed: R4.1, U2.6 (UD-)
unnamed: R5.2, U2.2 (TXD)
unnamed: R6.1, U2.3 (RXD)
unnamed: R17.2, SW1.2
unnamed: R18.2, SW2.2
unnamed: U1.6 (-), U1.7

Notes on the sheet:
LED Power
Pull-Up / Pull-Down
Chip Enable Pin
GPIO2 (D4) Buil-In led
LED WiFi
Conectado al boton de FLASH
Switches
Para borrado de datos WiFi
--------------- AUTO PROGRAM CIRCUIT --------------- DTR RTS RST GPIO0 --------------- 1 1 1 1 0 0 1 1 1 0 0 1 0 1 1 0
EQUIPO SERVIDOR
Reset por Software
LED LoRa
ALIMENTACION
LORA 915 MHz - RFM95
USB a UART
LEDs
Falla el booteo si pulled LOW
ESP12F / WiFi
Falla el booteo si pulled HIGH

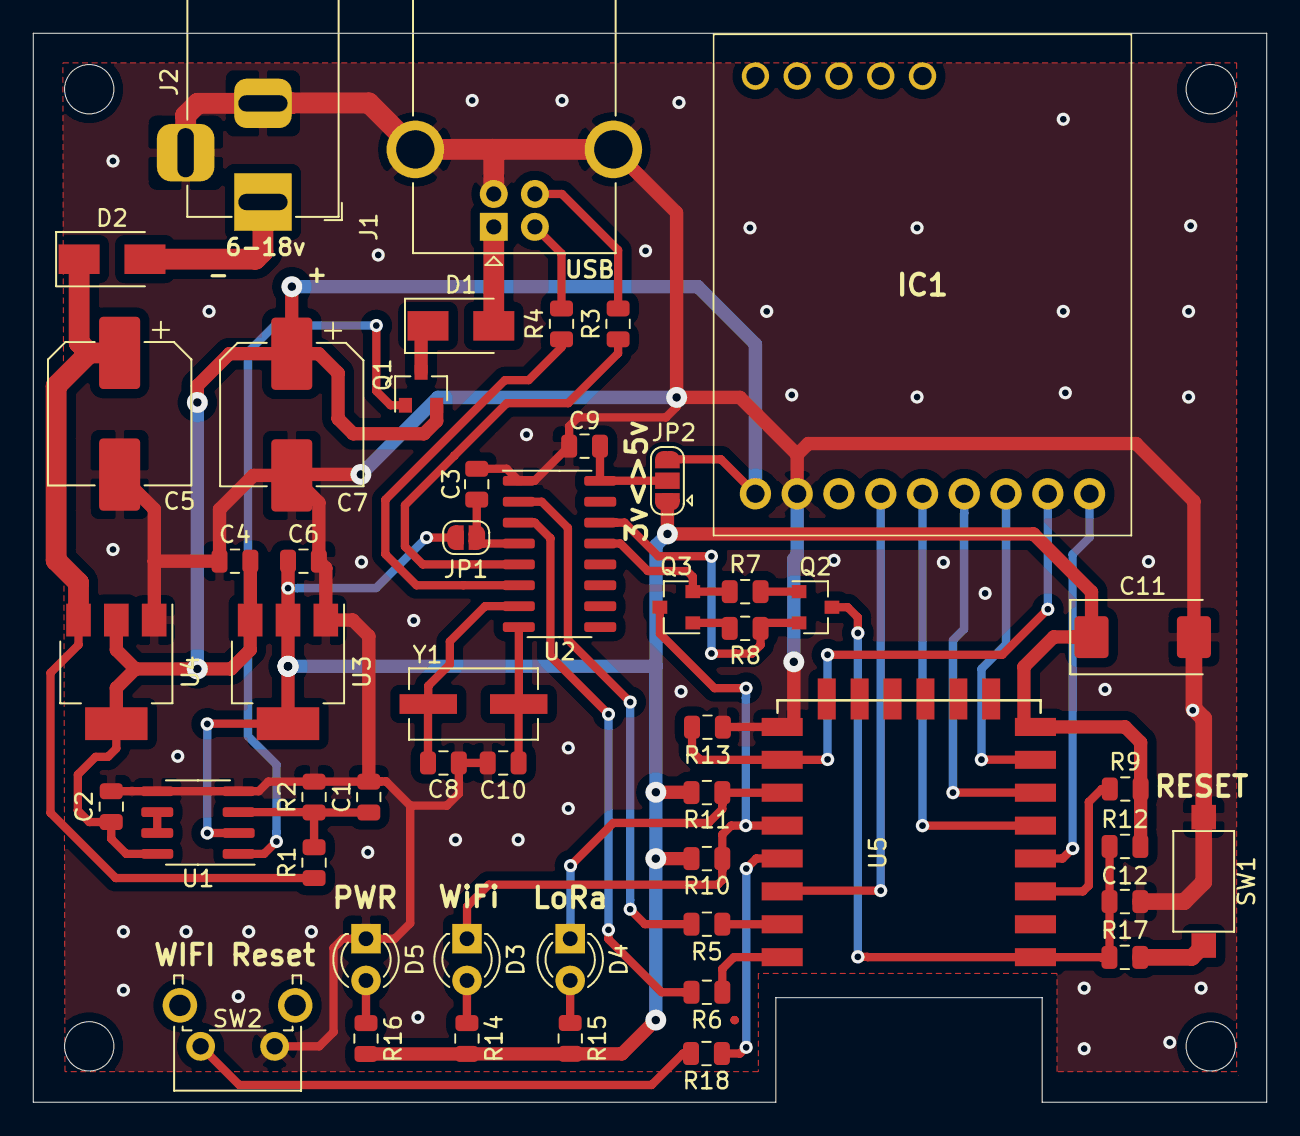
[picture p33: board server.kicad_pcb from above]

Board: 2 copper layers, 75.0 x 65.0 mm, 55 parts (0 on the bottom side), 42 nets.

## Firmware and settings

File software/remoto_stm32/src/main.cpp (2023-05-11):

//------------------------------------------------------------------------
//                                LIBRERIAS
//------------------------------------------------------------------------
#include <Arduino.h>

#include <RHReliableDatagram.h>
#include <RH_RF95.h>
#include <SPI.h>
//------------------------------------------------------------------------
//                                CONSTANTES
//------------------------------------------------------------------------
#define SERVER_ADDRESS  1         // Direccion del equipo Servidor
#define REMOTE_ADDRESS  2         // Direccion del equipo Remoto

#define BOOT1           PB2       // para condicion de arranque 

#define RFM95_CS        PA4       // Pin de CS del modulo SPI
#define RFM95_RST       PA3       // Pin de reset modulo Lora
#define RFM95_INT       PA2       // Pin de interrupcion para Rx Lora
#define LED_LORA        PC14      // Pin par indicar actividad de Tx/Rx
//#define LED_LORA        PC13    // Pin par indicar actividad de Tx/Rx
#define POWER_LORA      20        // Potencia de transmision (de 5 a 23)
#define RETRIES_LORA    3         // Cantidad de reintentos (de 3 a 6)
#define TIMEOUT_LORA    4         // Timeout entre reintentos (4 a 8)
#define RF95_FREQ       915.0     // Frecuencia del tranceptor Lora
#define CTE_TO_NORMAL   50        // CTE para ajustar el timeout
#define CTE_TO_SLOW     500      // CTE para ajustar el timeout en slow
#define TIEMPO          80000     // 80 segundos timeout para millis()
                                  // Definicion de pines de salida
#define PORT0           PB9       // para P1
#define PORT1           PB8       // para P2/P3
#define PORT2           PB7       // para P4
#define PORT3           PB6       // para P5/P6

#define LOGICA_NEGATIVA 1         // Logica neg para control de puertos
//------------------------------------------------------------------------
//                                 VARIABLES
//------------------------------------------------------------------------
char ver_soft[]   = "\nConmutador de Retorno v1.0";
char bienvenida[] = "----- Equipo Remoto -----\n";
char buf[RH_RF95_MAX_MESSAGE_LEN];

uint8_t  idport;                      //Id de puerto
bool     estado;                      //Estado del puerto variable aux
bool     gpio[4] = {0,0,0,0};         //Matriz de estado de los puertos
uint8_t  ports[4] = {PORT0, PORT1,    
                     PORT2, PORT3};   //Matriz de puertos
char     packet[14] = "updateGPIO.";  //Array de datos Lora 
uint8_t  i;                           //Contador
bool     rebooting = 1;               //Indica que el uC esta iniciando
bool     slow = false;                //Flag de modulación lenta
bool     refresh = false;
uint8_t  power = POWER_LORA;          //Potencia de tx LoRa 
uint8_t  retries = RETRIES_LORA;      //Cant. de reintentos p/ sendtoWait
uint16_t timeout = TIMEOUT_LORA;      //Timeout entre reintentos
uint16_t aux;
uint32_t previousMillis;
//------------------------------------------------------------------------
//                          FUNCIONES - CODIGO ANEXO
//------------------------------------------------------------------------
#include "RF95_Utils.hpp"      //Funciones para el manejo del modulo RFM95

//------------------------------------------------------------------------
//Imprime en consola de los datos recibidos por el modulo Lora junto con 
//los niveles de recepcion.
void printRcv(char *buf, uint8_t from_adr) {
  Serial.println(""); 
  Serial.print("De: 0x");
  Serial.print(from_adr, HEX);
  Serial.print("-> ");
  Serial.println((char*)buf);
  //RH_RF95::printBuffer("Trama completa: ", buf, len);
  Serial.print("RSSI: ");
  Serial.print(rf95.lastRssi(), DEC);
  Serial.print(", SNR: ");
  Serial.println(rf95.lastSNR(), DEC);  
}

//------------------------------------------------------------------------
//Envia estado actualizado de todos los puertos y los imprime en consola.
void updateGPIO(void) {                   
  for (i=0;i<4;i++) {    
    if(LOGICA_NEGATIVA)
      gpio[i] = !(digitalRead(ports[i]));   
    else
      gpio[i] = digitalRead(ports[i]);   

    itoa(i, packet+11, 10);
    itoa(gpio[i], packet+12, 10);
    packet[13] = 0;
    Serial.println(packet); 
    delay(10);
    send_lora();
    Serial.println("");     
  }  
}

//------------------------------------------------------------------------
//                                SETUP
//------------------------------------------------------------------------
void setup() {

  pinMode(BOOT1, INPUT); 
  pinMode(LED_LORA, OUTPUT);            //configuracion de pines
  digitalWrite(LED_LORA, HIGH);         
  pinMode(RFM95_RST, OUTPUT);
  digitalWrite(RFM95_RST, HIGH);
  
  if(digitalRead(BOOT1) == 1)
    while (!Serial);              //espera hasta que la consola este lista
  
  Serial.begin(115200);
  delay(1000);  
  Serial.println(ver_soft);  
  delay(10);
  Serial.println(bienvenida);

  for (i=0;i<4;i++) {           //Configuracion e inicializacion de pines
    pinMode(ports[i], OUTPUT);   
    if(LOGICA_NEGATIVA)       
      digitalWrite(ports[i], 0);    
    else
      digitalWrite(ports[i], 1);
  }  
  Serial.println("ON todos los puertos");
  
  InitRF95();                           //inicializacion del modulo RFM95
  delay(50);
}

//------------------------------------------------------------------------
//                                BUCLE PRINCIPAL
//------------------------------------------------------------------------
void loop() {

  if(rebooting){
    updateGPIO();         //Al reiniciar enviar estado de todos los puertos
    rebooting = 0;
  }
  if(((millis() - previousMillis) >= TIEMPO) && (slow == 1)) {
    if(refresh == 0) {              //si no se recibio el refresh <>...
      slow = 0;
      setModulation();            //volver a modulacion normal(por defecto)
    }
    refresh = 0;
    previousMillis = millis();
  }

  //-----------------------------  
  if (manager.available()) {      //Verificar si hay un mje LoRa disponible
    uint8_t len = sizeof(buf);
    uint8_t from, indice; 
    String rx;

    //recibo la trama y envio el acuse de recibo automaticamente
    if (manager.recvfromAck((uint8_t *)buf, &len, &from)) {   

      digitalWrite(LED_LORA, LOW);
      delay(50);                  
      printRcv(buf, from);               //imprimir en consola datos de rx
      digitalWrite(LED_LORA, HIGH);
            
      rx = String(buf);
      //----------------------------- Comando setGPIO
      if (rx.indexOf("setGPIO.") != -1) { 
        indice = rx.indexOf("setGPIO.");
        idport = rx.substring(indice+8, indice+9).toInt();
        estado = rx.substring(indice+9, indice+10).toInt();
        
        if(LOGICA_NEGATIVA)
          digitalWrite(ports[idport], (!estado)); 
        else
          digitalWrite(ports[idport], (estado));
      }      
      //----------------------------- Comando getGPIO
      else if (rx.indexOf("getGPIO") != -1) {
        Serial.println("");
        delay(50);    
        updateGPIO();            //envio updateGPIO de todos los puertos
      }
      //----------------------------- Comando txpower
      else if (rx.indexOf("txpower.") != -1) { 
        indice = rx.indexOf("txpower.");
        if(rx.substring(indice+9, indice+10) == 0)
          power = rx.substring(indice+8, indice+9).toInt();
        else {
          power = 10 * rx.substring(indice+8, indice+9).toInt();
          power += rx.substring(indice+9, indice+10).toInt();
        }
        rf95.setTxPower(power, false);
        Serial.print("setTxPower-> ");
        Serial.println(power, DEC);        
      }
      //----------------------------- Comando retries
      else if (rx.indexOf("retries.") != -1) { 
        indice = rx.indexOf("retries.");
        retries = rx.substring(indice+8, indice+9).toInt();   
        manager.setRetries(retries);
        Serial.print("setRetries-> ");
        Serial.println(retries, DEC);        
      }
      //----------------------------- Comando timeout
      else if (rx.indexOf("timeout.") != -1) {  
        indice = rx.indexOf("timeout.");
        timeout = rx.substring(indice+8, indice+9).toInt();           
        
        if(slow)
          aux = timeout * CTE_TO_SLOW;
        else
          aux = timeout * CTE_TO_NORMAL;
        manager.setTimeout(aux);   
        Serial.print("setTimeout-> ");
        Serial.println(aux, DEC);        
      }
      //----------------------------- Comando setMOD
      else if (rx.indexOf("setMOD.") != -1) {
        indice = rx.indexOf("setMOD.");
        slow = rx.substring(indice+7, indice+8).toInt();      
        setModulation();
        previousMillis = millis();
      }
      //----------------------------- Comando refresh
      else if (rx.indexOf("<>") != -1) {
        refresh = 1;        
      }
    }
  } 
}

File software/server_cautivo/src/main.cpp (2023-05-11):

//------------------------------------------------------------------------
//                                LIBRERIAS
//------------------------------------------------------------------------
#include <Arduino.h>
#include <ESP8266WiFi.h>
#include <ESPAsyncWebServer.h>
#include <ArduinoJson.h>
#include <RHReliableDatagram.h>
#include <RH_RF95.h>
#include <SPI.h>
#include <Ticker.h>
#include <ESPAsyncWiFiManager.h> 

//#define USE_LittleFS            
#ifdef USE_LittleFS
	#include <FS.h>
	#define SPIFFS LittleFS
	#include <LittleFS.h> 
#else
  #include <FS.h>
#endif
//------------------------------------------------------------------------
//                                CONSTANTES
//------------------------------------------------------------------------
#define LED_WIFI        0         //Led de estado de conexion WIFI (D3)
#define TRIGGER_PIN     4         //Acceso al portal cautivo (D2)

#define SERVER_ADDRESS  1         //Direccion del equipo Servidor
#define REMOTE_ADDRESS  2         //Direccion del equipo Remoto
                                  //CLK (D5), MISO (D6), MOSI (D7)
#define RFM95_CS        15        //Pin de CS del modulo SPI    (D8)
#define RFM95_RST       16        //Pin de reset modulo Lora   (D0)
#define RFM95_INT       5         //Pin de interrupcion para Rx Lora (D1)
#define LED_LORA        2         //Indicador de actividad de Tx/Rx (D4)
#define POWER_LORA      20        //Potencia de transmision (entre 3 y 23)
#define RETRIES_LORA    3         //Cantidad de reintentos (de 3 a 6) 
#define TIMEOUT_LORA    4         //Timeout entre reintentos (de 4 a 8)
#define RF95_FREQ       915.0     //Frecuencia del tranceptor Lora
#define CTE_TO_NORMAL   50        //CTE para ajustar el timeout
#define CTE_TO_SLOW     500      //CTE para ajustar el timeout en slow
#define SCAN_WIFI       1         //Escaneo de redes WiFi en el inicio
//------------------------------------------------------------------------
//                                 VARIABLES
//------------------------------------------------------------------------
char ver_soft[] = "Conmutador de Retorno v1.0";
char bienvenida[] = "---- Equipo Servidor ----";

bool reboot = false;                //Flag de reinicio del servidor web
bool slow = false;                  //Flag de modulacion lenta
bool switch_modulation = false;     //P/ realizar el cambio de modulacion
bool ws_connect = false;            //actualiza estado al conectar un cliente WS

StaticJsonDocument<300> doc;        //para serializar y deserializar json

String  comando = "";               //comando recibido a ejecutar
uint8_t idport;                     //id de puerto
String  texto;                      //descripcion del puerto
bool    estado;                     //estado del puerto variable auxiliar
uint8_t valor;                      //valor enviado en los comandos
bool    ack = 0;                    //envio de ACK por ws
int16_t rssi;
uint8_t txpower = POWER_LORA;       //potencia de tansmision lora [5-20]
uint8_t retries = RETRIES_LORA;     //cantidad de reintentos [3-6]
uint8_t timeout = TIMEOUT_LORA;     //timeout entre reintentos [4-8]
uint16_t aux;

bool    gpio[4] = {0,0,0,0};        //matriz de estado de los puertos
char    packet[12] = "";            //string de Tx Lora
char    buf_rx_lora [15];           //string de Rx Lora
uint8_t len = sizeof(buf_rx_lora);  //tamano del string

Ticker ticker;                //Objeto para control del led de estado WiFi
//------------------------------------------------------------------------
//                          FUNCIONES - CODIGO ANEXO
//------------------------------------------------------------------------
//Callback para control del LED de estado de WiFi.
void tick(void) {  
  bool state = digitalRead(LED_WIFI);    
  digitalWrite(LED_WIFI, !state);             
}

//------------------------------------------------------------------------
//Devuelve el texto descriptivo del puerto segun el id.
String text_pin(uint8_t id) {
    String desc;

    switch(id) {
    case 0:
      desc = "P1";
      break;
    case 1:
      desc = "P3";
      break;
    case 2:
      desc = "P4";
      break;
    case 3:
      desc = "P6";
      break;
    default:
      break;          
  }
  return desc;
}

//------------------------------------------------------------------------
#include "config.h"              //Datos de la red y coneccion
#include "ESP8266_Utils.hpp"     //Func. para manejo de WiFi en STA y AP
#include "WebSockets.hpp"        //Func. para comunicacion WebSockets
#include "Server.hpp"            //Func. para el manejo del servidor web
#include "ESP8266_Utils_AWS.hpp" //Inicializacion y eventos por WS
#include "RF95_Utils.hpp"        //Func. para el manejo del modulo RFM95
//------------------------------------------------------------------------
//Imprime en consola los datos de la recepcion LoRa y niveles de señal.
void printRcv(char *buf, uint8_t from_adr) {
  Serial.print("De: 0x");
  Serial.print(from_adr, HEX);
  Serial.print("-> ");
  Serial.println((char*)buf_rx_lora);
  Serial.print("RSSI: ");
  Serial.print(rf95.lastRssi(), DEC);
  Serial.print(", SNR: ");
  Serial.println(rf95.lastSNR(), DEC);      
}

//------------------------------------------------------------------------
//Secuencia para el borrado de credenciales WiFi al activar TRIGGER_PIN.
void delete_wifi(void) {  
  delay(60);                                //Retardo para evitar rebotes
  if(digitalRead(TRIGGER_PIN) == LOW) {
    Serial.println("Botón presionado."); 
    delay(2000);                         //Espera de 4 seg para el borrado
    delay(2000);      
    if(digitalRead(TRIGGER_PIN) == LOW) {
      Serial.println("Botón retenido.");
      Serial.println("Borrando credenciales...");      
      Serial.println("Reiniciando...");              
      WiFi.mode(WIFI_AP_STA);         //para borrar debe estar en modo STA
      WiFi.persistent(true);
      WiFi.disconnect(true);
      WiFi.persistent(false);        
      delay(1000);
      ESP.restart();         
    }      
  }
}
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
